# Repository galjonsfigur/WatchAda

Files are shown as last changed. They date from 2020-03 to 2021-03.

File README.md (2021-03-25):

# Ada-powereded digital watch

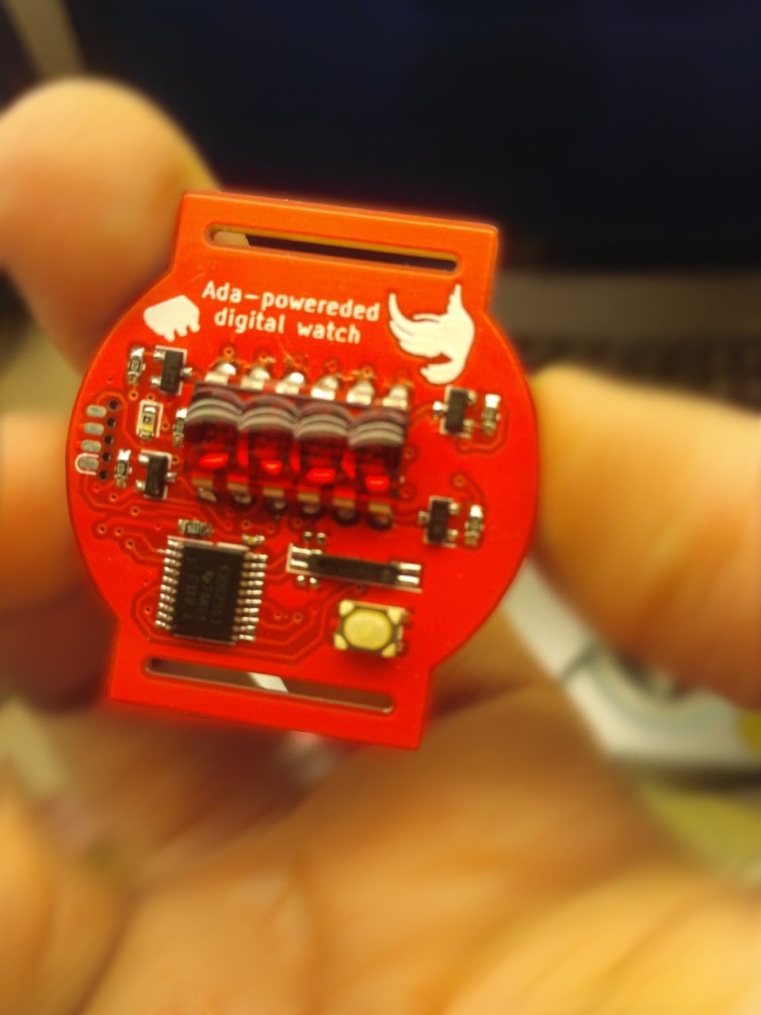
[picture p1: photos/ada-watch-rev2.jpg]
Digital watch


This repository contains Schematics, KiCad design files and software for Ada-powereded digital watch.
It uses wonderful work of [msp430-ada project](https://sourceforge.net/projects/msp430ada/) by Brian Drummond.
Software for this watch is a modification of original project and adds missing
features like automatic brightness, temperature reading and Easter Egg.

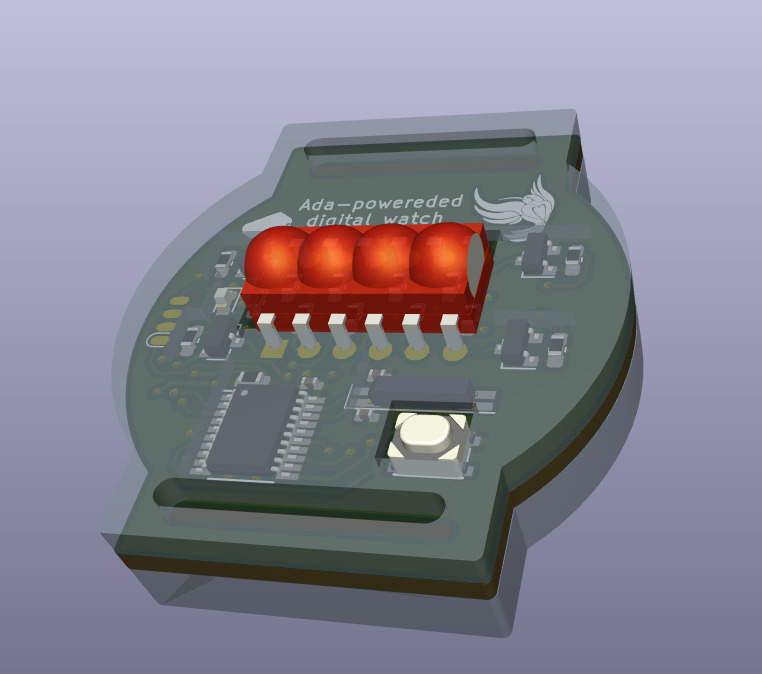
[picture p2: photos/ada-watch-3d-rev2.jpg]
Digital watch 3D view


Revision 1 of the PCB was tested and following problems have been found:

- Incorrect footprint of CR2032 Battery holder
- THT Crystal footprint is too big and will be replaced with Epson MC-146 32kHz Crystal

Revision 2 fixed those problems and after about year of testing it haven't showed other flaws.
More photos and renders can be found in `photos` folder.

GCC compiler for building this project can be found in this repository. It was built on CentOS 6 x64 and should work with any modern 64-bit GNU/Linux distribution.
Docker image for it is still in progress as it requires exact same version of host GCC and patches from MSP430-Ada project.

## BOM and assembly instructions
Interactive BOM can be found [here](hardware/rev2/bom/ibom.html).

Remember to start with SMD components. Program the MSP430, put the display in place and
test it before soldering it to the board.

Case can be 3D printed with semi-transparent material or cut from thin PMMA.

The best way to program the microcontroller is to use [SOICBite](https://github.com/SimonMerrett/SOICbite) connected
to MSP430-G2 Launchpad. Pin layout can be found in the schematic and only TEST, RST, GND and 3V need to be used to program it.
After connecting the SOICBite, `make flash` command can be used. It uses `mspdebug` program and works only on GNU/Linux environment.
The firmware binary can be found in `firmware/obj` folder.

# License
GPL (Same as MSP430-Ada project)

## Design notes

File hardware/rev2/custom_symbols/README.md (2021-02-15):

# Third-party symbols used in this design:

- [SOICBite](https://github.com/SimonMerrett/SOICbite)
- [SKRPACE010](https://github.com/nosuz/kicad-lib) (footprint only)
- [MC146 Crystal](https://grabcad.com/library/crystal-smd-seikoepson-mc146-4pin-6-7x1-5mm-1)

Rest of the files were designed for this project by its author.

This folder also contains fused model of the case to be able to see how it would
align with the PCB - to display it [this](custom_case_fused.step) 3D model has
to be attached to any component and aligned.

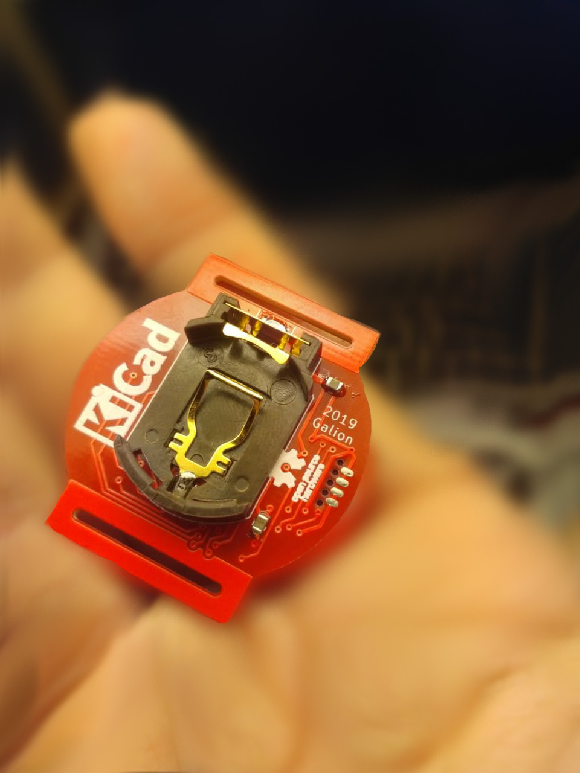
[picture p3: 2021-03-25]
photos/ada-watch-back-rev2.jpg

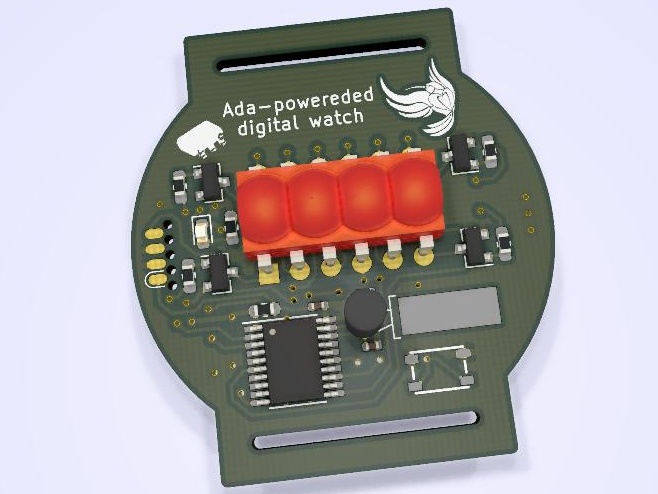
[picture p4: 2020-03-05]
photos/ada-watch-3d-rev1.jpg

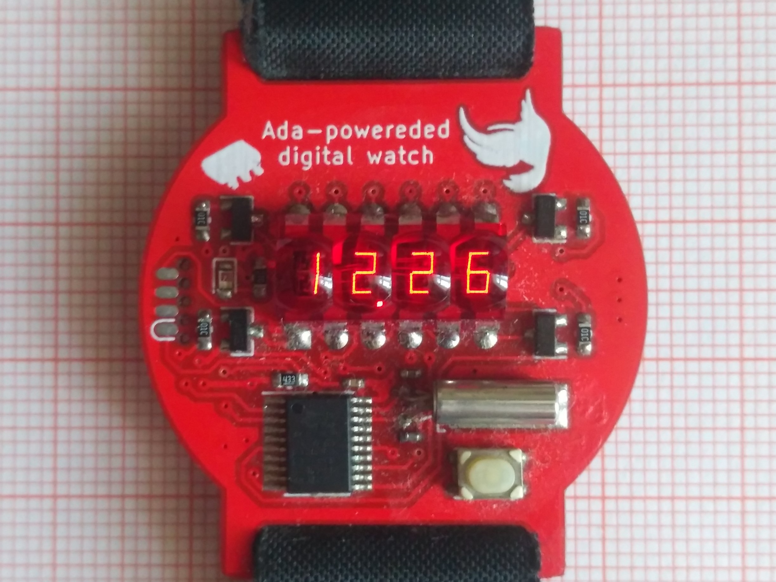
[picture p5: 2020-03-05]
photos/front-rev1.jpg

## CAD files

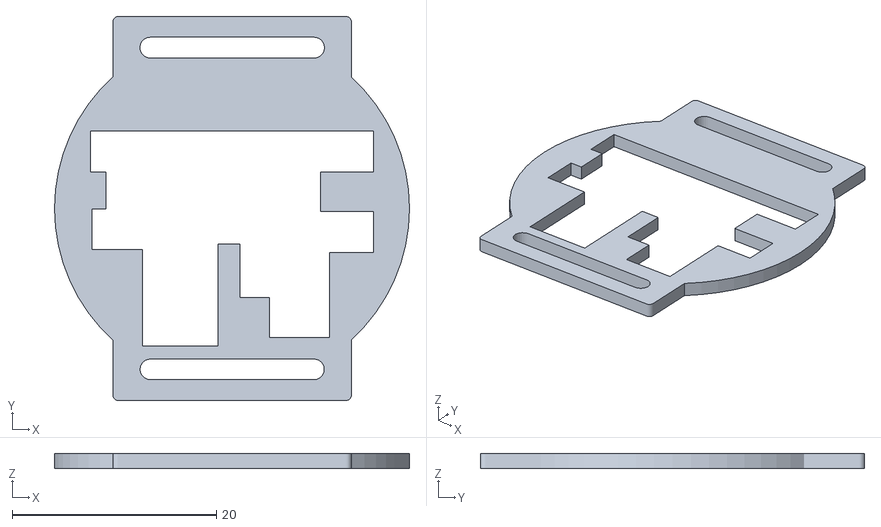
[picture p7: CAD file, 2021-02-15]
case/Front_PCB.obj
34.8 x 37.6 x 1.50

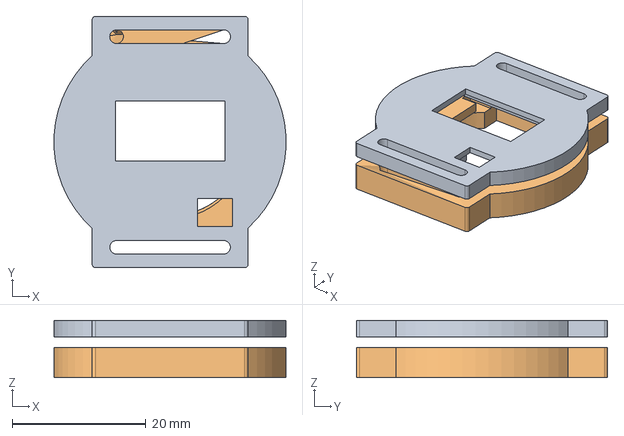
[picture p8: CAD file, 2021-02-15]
hardware/rev2/custom_symbols/custom_case_fused.step
34.7 x 37.6 x 8.60 mm

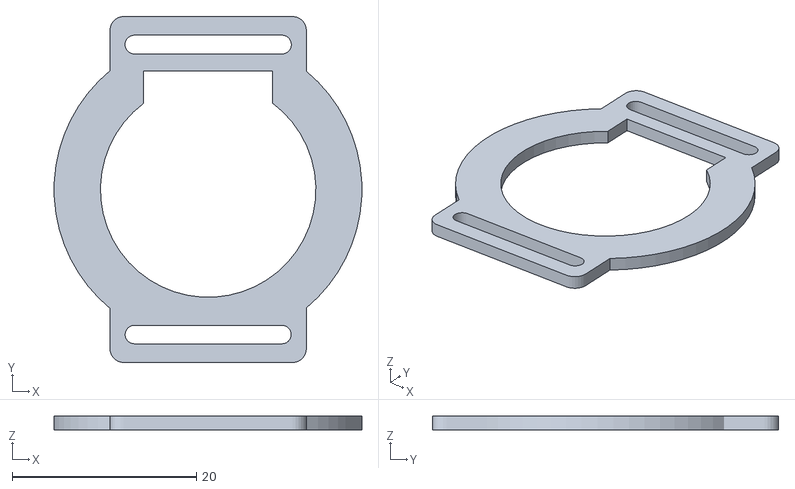
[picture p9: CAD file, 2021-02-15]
case/Back_Middle_Cover.obj
33.4 x 37.6 x 1.50

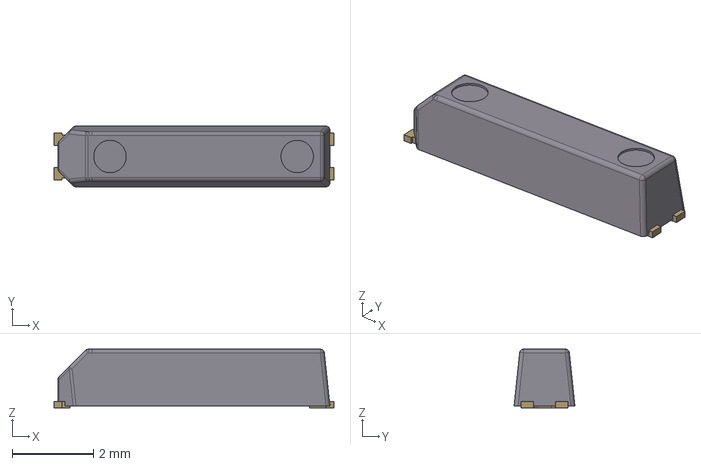
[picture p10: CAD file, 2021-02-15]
hardware/rev2/custom_symbols/Crystal_SMD_SeikoEpson_MC146-4Pin_6.7x1.5mm.step
6.90 x 1.50 x 1.45 mm

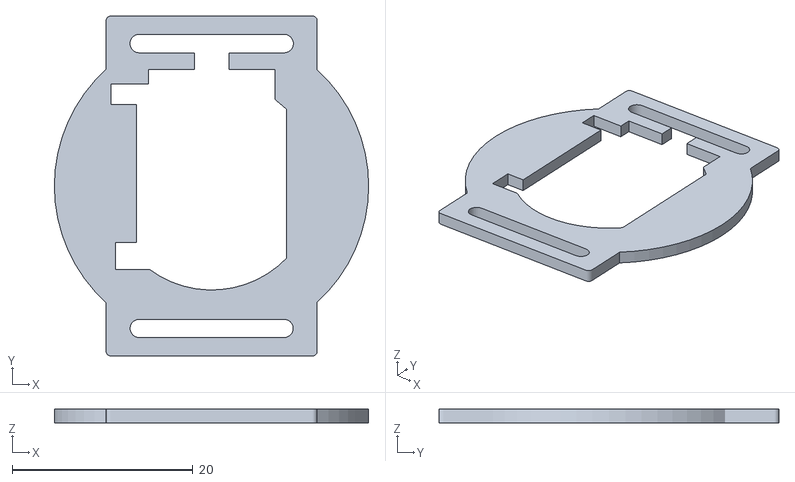
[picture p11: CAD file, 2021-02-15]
case/Back_PCB_Cover.obj
34.8 x 37.6 x 1.50

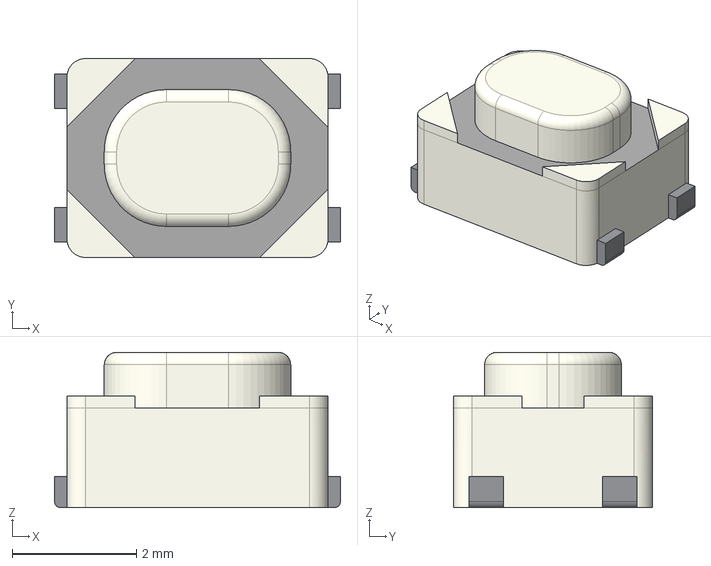
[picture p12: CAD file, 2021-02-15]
hardware/rev2/custom_symbols/SKRPACE010.step
4.60 x 3.20 x 2.50 mm

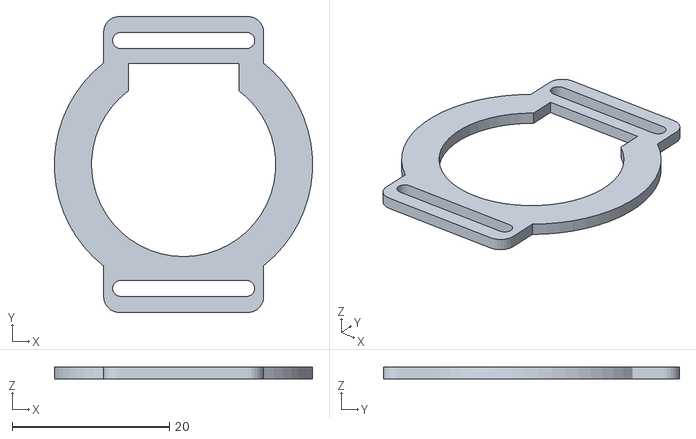
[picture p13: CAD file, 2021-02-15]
case/Back_Battery_Cover.obj
32.8 x 37.6 x 1.50

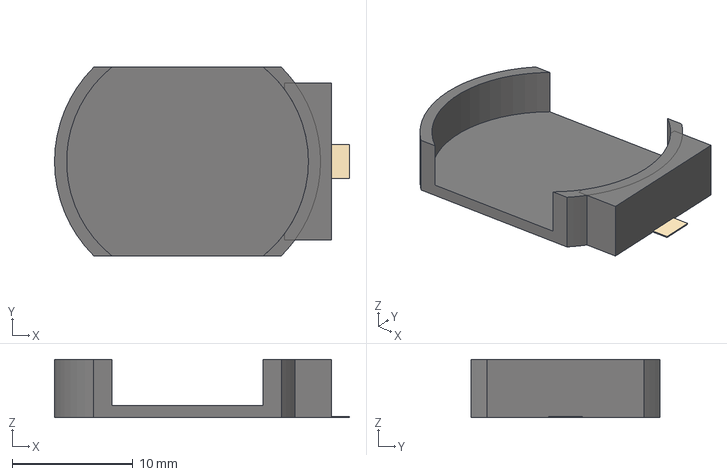
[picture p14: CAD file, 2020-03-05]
hardware/rev2/custom_symbols/CR2032_780-72-00GF51.step
24.4 x 15.6 x 4.80 mm

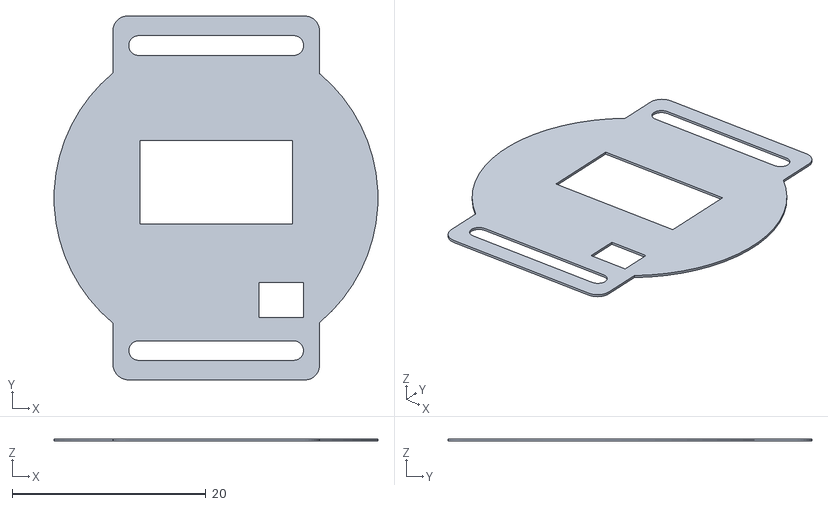
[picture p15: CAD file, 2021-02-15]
case/Front_Cover.obj
33.4 x 37.6 x 0.25

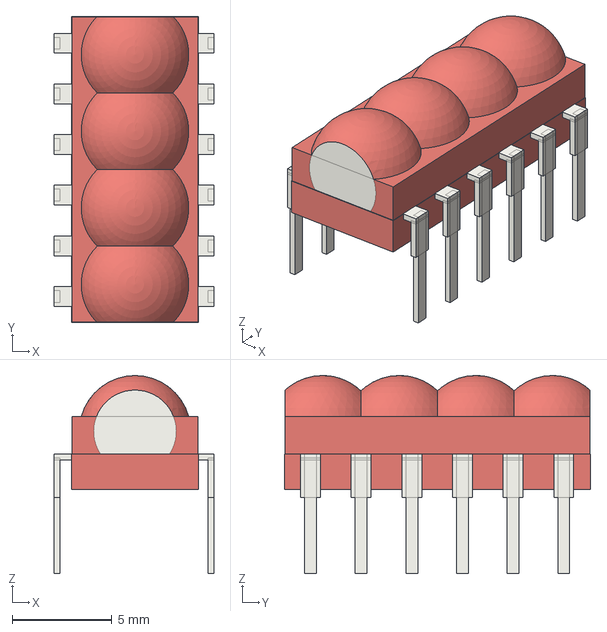
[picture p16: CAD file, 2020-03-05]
hardware/rev2/custom_symbols/HP5082-74x4.step
8.00 x 15.4 x 9.93 mm

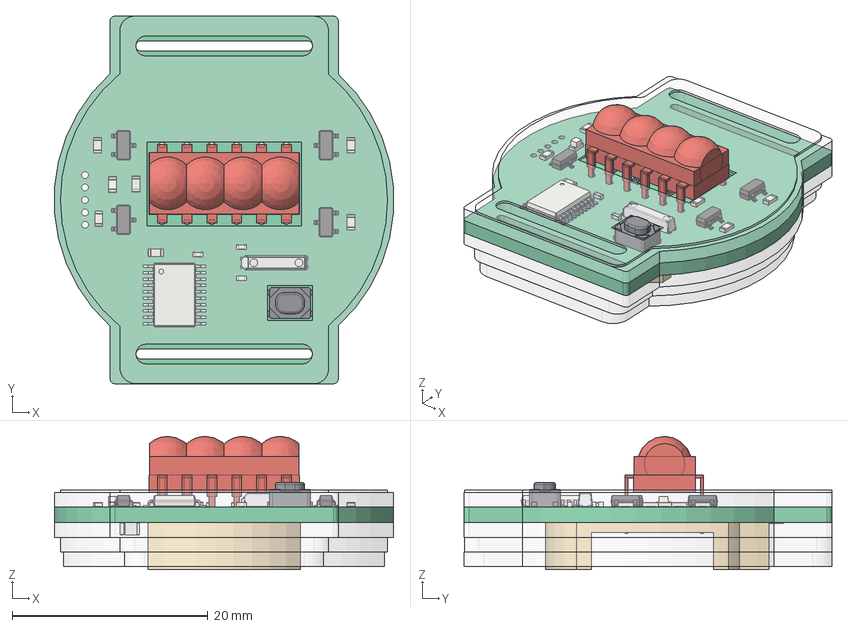
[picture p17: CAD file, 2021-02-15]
case/case.FCStd
34.7 x 37.6 x 13.6 mm
Pcb
"Y1"_Crystal_SMD_SeikoEpson_MC146-4Pin_6.7x1.5mm_00000000-0000-0000-0000-00005d9e574c[2]
"U1"_union_00000000-0000-0000-0000-00005d9e570d
"R9"_R_0603_1608Metric_00000000-0000-0000-0000-00005d9e5678
"U2"_TSSOP_20_44x65mm_P065mm_00000000-0000-0000-0000-00005d9e5731
"SW1"_SKRPACE101_00000000-0000-0000-0000-00005d9e56dd
"R14"_R_0603_1608Metric_00000000-0000-0000-0000-00005d9e56cd
"R13"_R_0603_1608Metric_00000000-0000-0000-0000-00005d9e56bc
"R12"_R_0603_1608Metric_00000000-0000-0000-0000-00005d9e56ab
"R11"_R_0603_1608Metric_00000000-0000-0000-0000-00005d9e569a
"R10"_R_0603_1608Metric_00000000-0000-0000-0000-00005d9e5689
"R8"_R_0603_1608Metric_00000000-0000-0000-0000-00005d9e5667
"R7"_R_0603_1608Metric_00000000-0000-0000-0000-00005d9e5656
"R6"_R_0603_1608Metric_00000000-0000-0000-0000-00005d9e5645
"R5"_R_0603_1608Metric_00000000-0000-0000-0000-00005d9e5634
"R4"_R_0603_1608Metric_00000000-0000-0000-0000-00005d9e5623
"R3"_R_0603_1608Metric_00000000-0000-0000-0000-00005d9e5612
"R2"_R_0603_1608Metric_00000000-0000-0000-0000-00005d9e5601
"R1"_R_0603_1608Metric_00000000-0000-0000-0000-00005d9e55f0
"Q5"_LED_0603_1608Metric_00000000-0000-0000-0000-00005da37bf8
"Q4"_SOT_23_00000000-0000-0000-0000-00005d9e55cc
"Q3"_SOT_23_00000000-0000-0000-0000-00005d9e55b7
"Q2"_SOT_23_00000000-0000-0000-0000-00005d9e55a2
"Q1"_SOT_23_00000000-0000-0000-0000-00005d9e558d
"C5"_C_0402_1005Metric_00000000-0000-0000-0000-00005d9e5560
"C4"_C_0402_1005Metric_00000000-0000-0000-0000-00005d9e5551
"C3"_C_0402_1005Metric_00000000-0000-0000-0000-00005d9e5542
"BT1"_union001_00000000-0000-0000-0000-00005e064094
"C2"_C_0805_2012Metric_00000000-0000-0000-0000-00005d9e5533
"C1"_C_0805_2012Metric_00000000-0000-0000-0000-00005d9e5522

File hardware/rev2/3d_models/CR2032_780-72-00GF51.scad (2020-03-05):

translate([-1.7, 0, 0])
union() {
    color("Black") intersection(){
        translate([-11.895, -7.8]) cube([23.79, 15.6, 4.8]);
        difference() {
            union() {           
                cylinder(h=4.8, d=22);
                translate([8, -6.5, 0]) cube([4.79, 13, 4.8]);
            }
                translate([0, 0, 1]) cylinder(h=3.8, d=20);    
        }
    }
    color("Gold") {
        translate([-10.5, -0.9, 0]) cube([4, 1.8, 0.1]);
     translate([22.79/2, -1.4, 0]) cube([2, 2.8, 0.1]);   
    }
}

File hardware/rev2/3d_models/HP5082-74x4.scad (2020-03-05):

rotate([0,0,90])
translate([-6.35, -3.81 ,1.78/2])
union() {
    color("Red") {
    cube([15.37, 6.35, 1.78], center=true);
    translate([0, 0, 1.78])
    cube([15.3, 6.3, 2], center=true);
    intersection(){
    for(i = [0:3]) {
        translate([-15.37/2+1.92125+i*1.92125*2, 0, 2.03])
            color("Red") sphere(r=2.8, $fn=50);
    }
    cube([15.3, 6.3, 15], center=true);
    }
}
    translate([-5.08 - 2.54, 0, -0.9])
    for (i = [0:5]) {
    color("Silver") translate([i*2.54,-3.5,0]) {
    	translate([1.252 - 0.5, -0.45, 1.5])
    	    cube([1, 5, 0.3]);
    	translate([1.252-0.5, 2.55, 1.5])
    	    cube([1, 5, 0.3]);
    	translate([1.252-0.3, -0.45, -4.2])
            cube([0.6, 0.3, 6]);
    	translate([1.252 - 0.3, 7.25,-4.2])
            cube([0.6, 0.3, 6]);
    	translate([1.252 - 0.5, -0.45, -0.4])
            cube([1, 0.3, 2]);
    	translate([1.252 - 0.5, 7.25, -0.4])
            cube([1, 0.3, 2]);
    }
}
 
}

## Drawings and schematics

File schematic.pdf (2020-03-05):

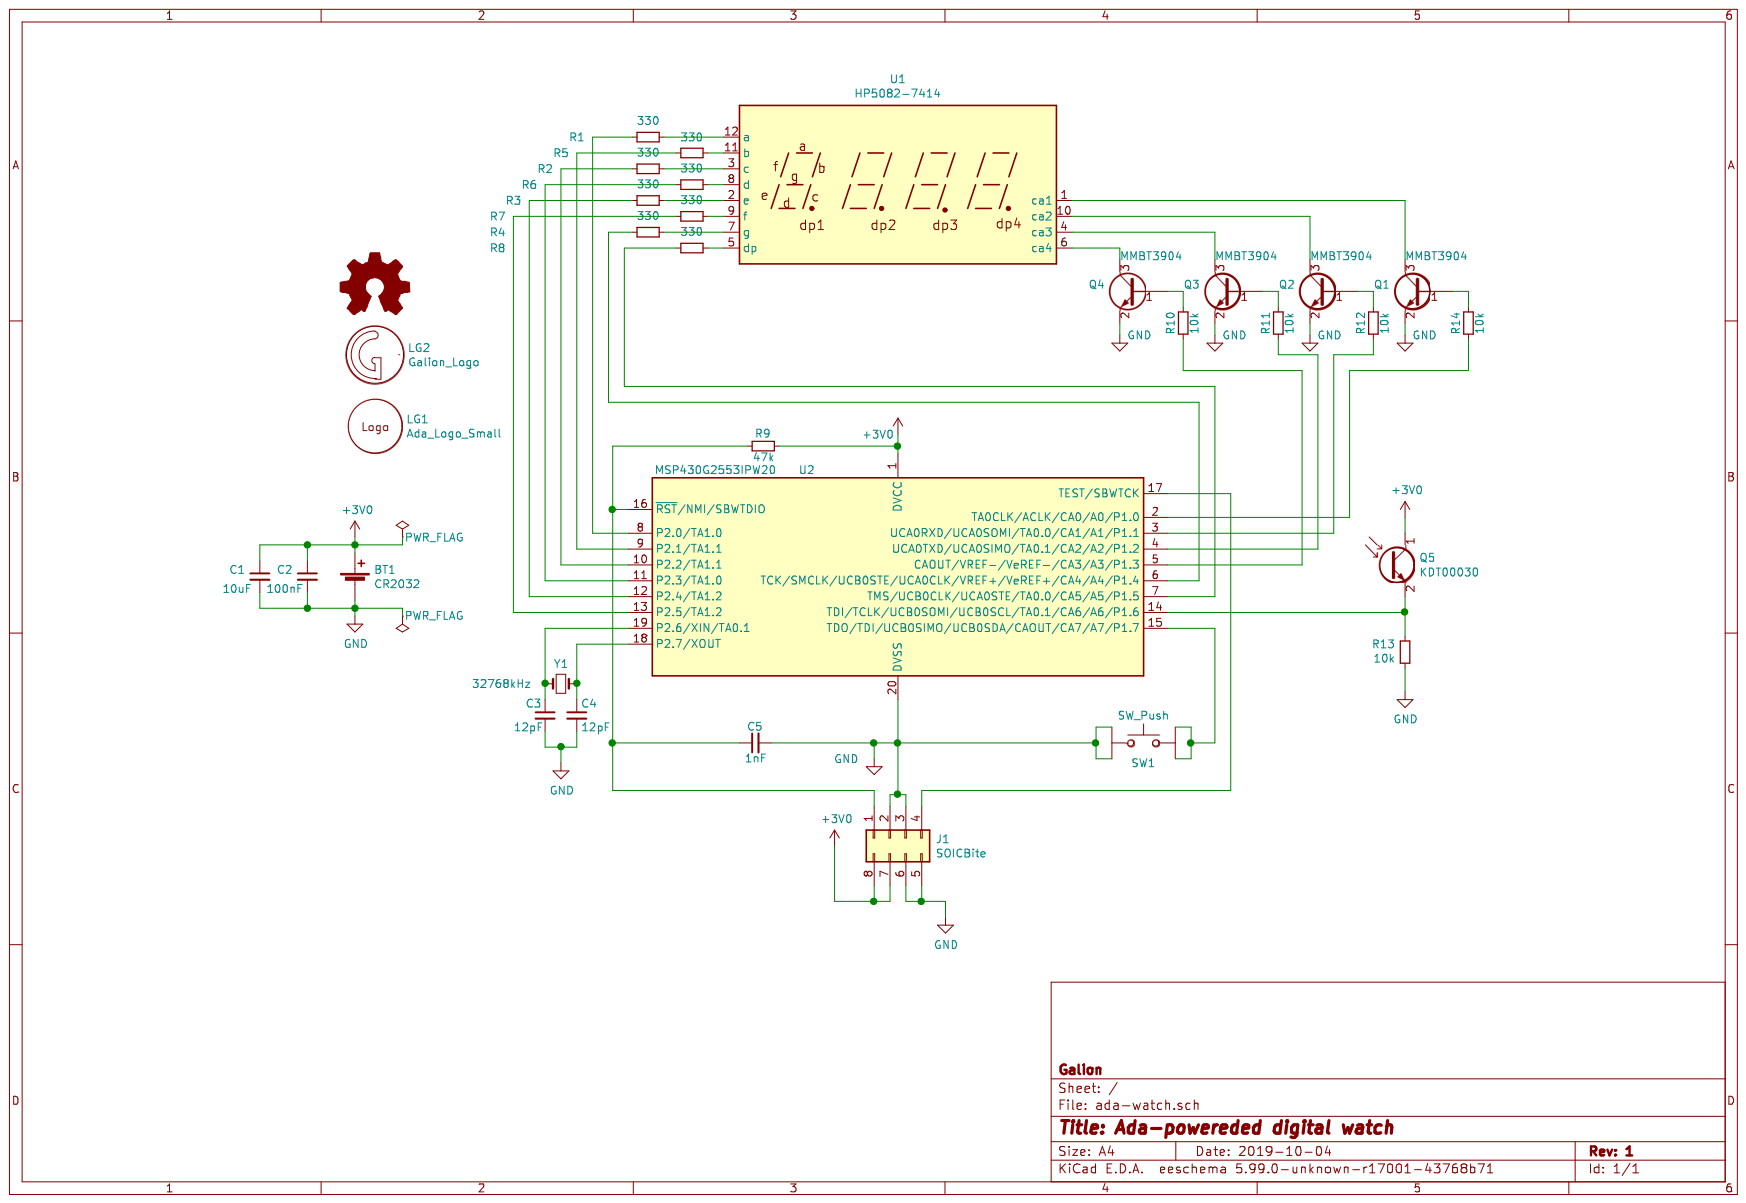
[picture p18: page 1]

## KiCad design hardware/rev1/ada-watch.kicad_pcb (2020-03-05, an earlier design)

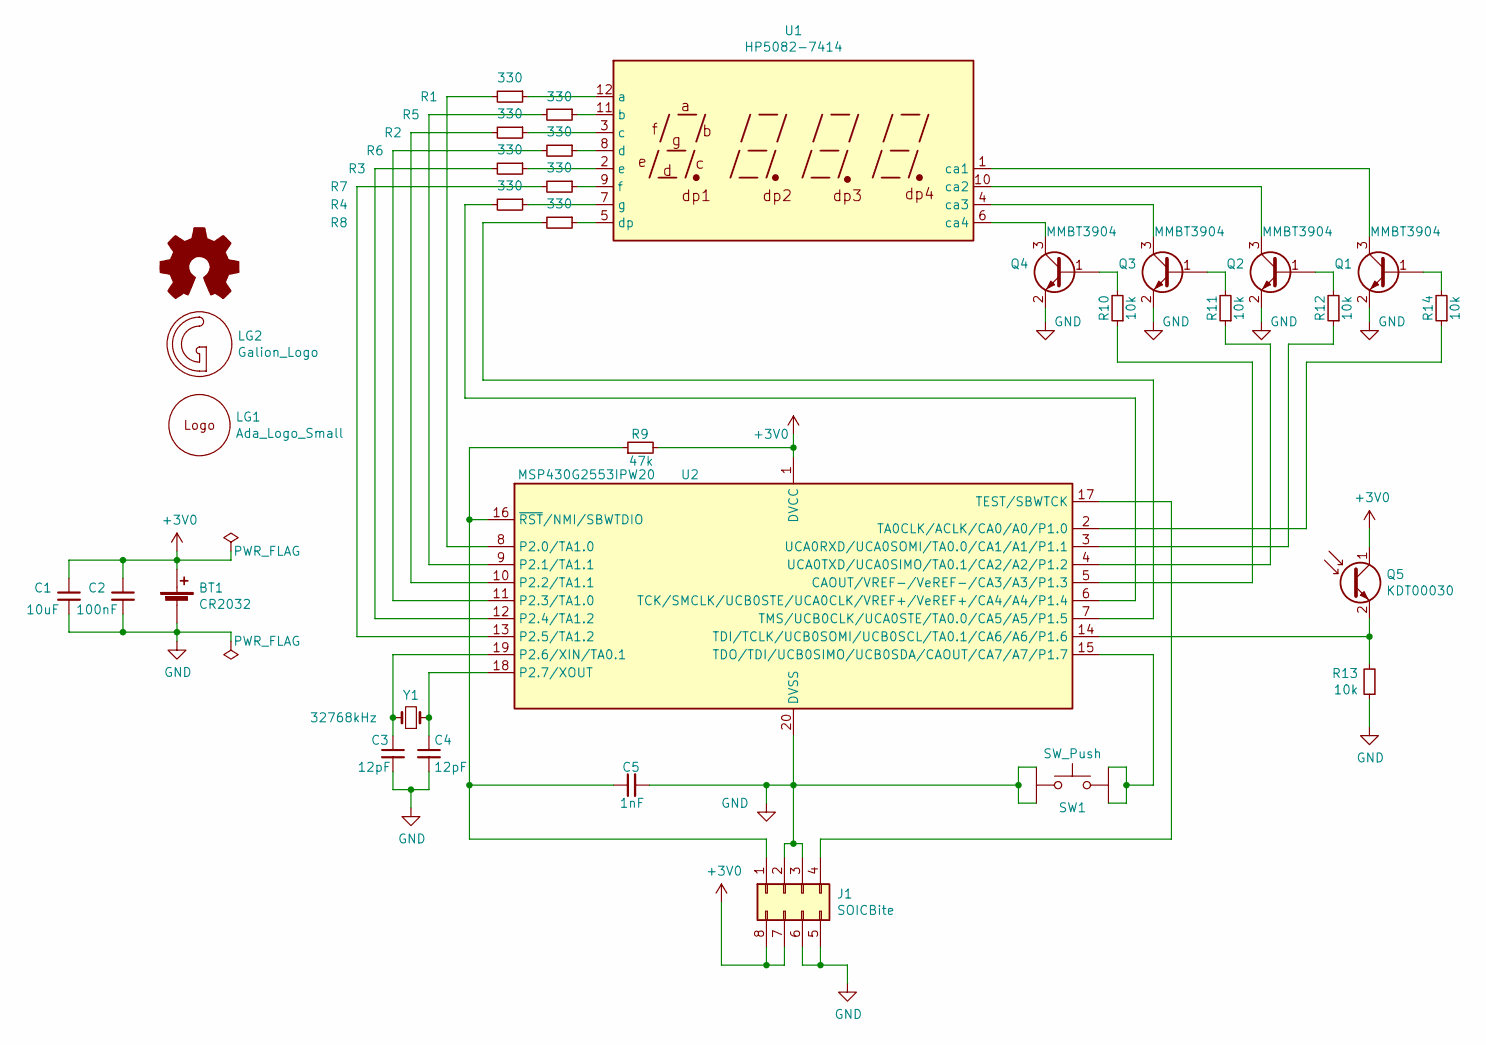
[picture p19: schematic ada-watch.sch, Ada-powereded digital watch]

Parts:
BT1: CR2032; BatteryHolder_Pinrex_780-72-00GF51_1x2032_customSilk
C1: 10uF; C_0805_2012Metric
C2: 100nF; C_0805_2012Metric
C3, C4: 12pF; C_0402_1005Metric
C5: 1nF; C_0402_1005Metric
J1: SOICBite; SOIC_clipProgSmall
LG1: Ada_Logo_Small
LG2: Galion_Logo; Galion_Logo_Small
LG3: Logo_Open_Hardware_Small; OSHW-Symbol_6.7x6mm_SilkScreen
Q1, Q2, Q3, Q4: MMBT3904; SOT-23
Q5: KDT00030; LED_0603_1608Metric
R1, R2, R3, R4, R5, R6, R7, R8: 330; R_0603_1608Metric_Pad1.05x0.95mm_HandSolder
R9: 47k; R_0603_1608Metric
R10, R11, R12, R13, R14: 10k; R_0603_1608Metric_Pad1.05x0.95mm_HandSolder
SW1: SW_Push; SKRPACE010
U1: HP5082-7414; DIP-12_W7.62mm_CustomPads_NoSilk
U2: MSP430G2553IPW20; TSSOP-20_4.4x6.5mm_P0.65mm
Y1: 32768kHz; Crystal_C38-LF_D3.0mm_L8.0mm_Horizontal_1EP_style1

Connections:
+3V0: BT1.1 (+), C1.1, C2.1, J1.7, J1.8, Q5.1 (C), R9.2, U2.1 (DVCC)
GND: BT1.2 (-), C1.2, C2.2, C3.2, C4.2, C5.2, J1.2, J1.3, J1.5, J1.6, Q1.2 (E), Q2.2 (E), Q3.2 (E), Q4.2 (E), R13.1, SW1.3, SW1.4, U2.20 (DVSS)
unnamed: C3.1, U2.19 (P2.6/XIN/TA0.1), Y1.2
unnamed: C4.1, U2.18 (P2.7/XOUT), Y1.1
unnamed: C5.1, J1.1, R9.1, U2.16 (~RST~/NMI/SBWTDIO)
unnamed: J1.4, U2.17 (TEST/SBWTCK)
unnamed: Q1.1 (B), R14.2
unnamed: Q1.3 (C), U1.1 (ca1)
unnamed: Q2.1 (B), R12.2
unnamed: Q2.3 (C), U1.10 (ca2)
unnamed: Q3.1 (B), R11.2
unnamed: Q3.3 (C), U1.4 (ca3)
unnamed: Q4.1 (B), R10.2
unnamed: Q4.3 (C), U1.6 (ca4)
unnamed: Q5.2 (E), R13.2, U2.14 (TDI/TCLK/UCB0SOMI/UCB0SCL/TA0.1/CA6/A6/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)
unnamed: R1.1, U1.12 (a)
unnamed: R1.2, U2.8 (P2.0/TA1.0)
unnamed: R2.1, U1.3 (c)
unnamed: R2.2, U2.10 (P2.2/TA1.1)
unnamed: R3.1, U1.2 (e)
unnamed: R3.2, U2.12 (P2.4/TA1.2)
unnamed: R4.1, U1.7 (g)
unnamed: R4.2, U2.6 (TCK/SMCLK/UCB0STE/UCA0CLK/VREF+/VeREF+/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)
unnamed: R5.1, U1.11 (b)
unnamed: R5.2, U2.9 (P2.1/TA1.1)
unnamed: R6.1, U1.8 (d)
unnamed: R6.2, U2.11 (P2.3/TA1.0)
unnamed: R7.1, U1.9 (f)
unnamed: R7.2, U2.13 (P2.5/TA1.2)
unnamed: R8.1, U1.5 (dp)
unnamed: R8.2, U2.7 (TMS/UCB0CLK/UCA0STE/TA0.0/CA5/A5/P1.5)
unnamed: R10.1, U2.5 (CAOUT/VREF-/VeREF-/CA3/A3/P1.3)
unnamed: R11.1, U2.4 (UCA0TXD/UCA0SIMO/TA0.1/CA2/A2/P1.2)
unnamed: R12.1, U2.3 (UCA0RXD/UCA0SOMI/TA0.0/CA1/A1/P1.1)
unnamed: R14.1, U2.2 (TA0CLK/ACLK/CA0/A0/P1.0)
unnamed: SW1.1, SW1.2, U2.15 (TDO/TDI/UCB0SIMO/UCB0SDA/CAOUT/CA7/A7/P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)

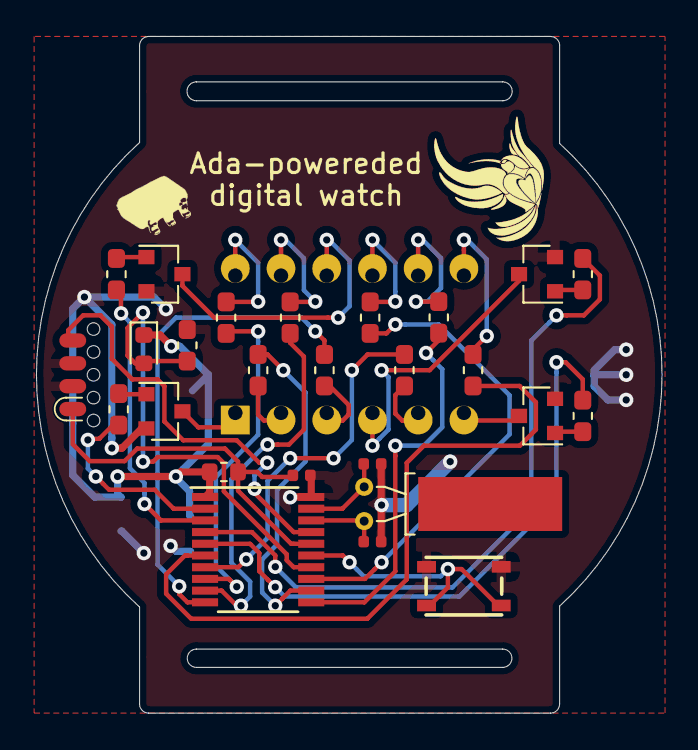
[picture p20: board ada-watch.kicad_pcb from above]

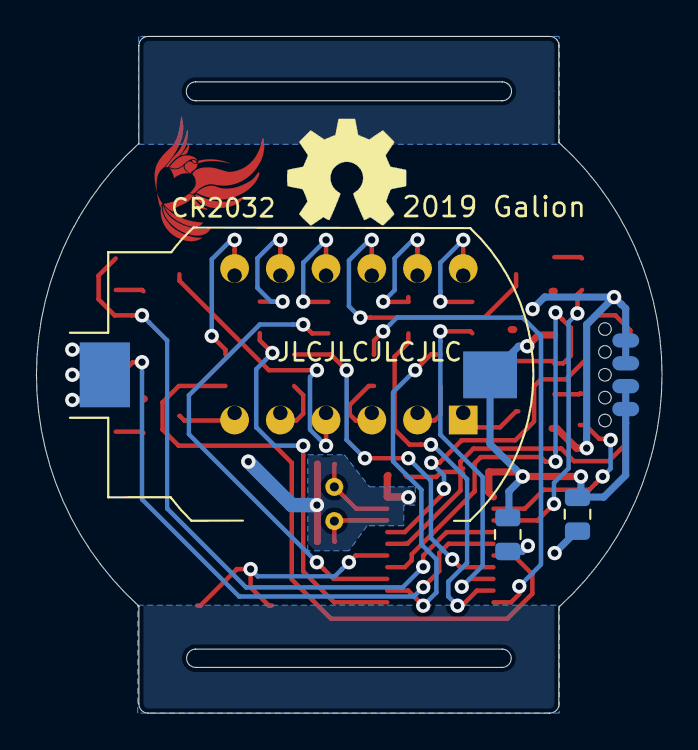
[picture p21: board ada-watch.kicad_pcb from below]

Board: 2 copper layers, 34.8 x 37.6 mm, 33 parts (4 on the bottom side), 36 nets.

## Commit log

2021-02-15 Add revision 2 of the PCB
    [CR2032_780-72-00GF51.scad, CR2032_780-72-00GF51.step, Crystal_SMD_SeikoEpson_MC146-4Pin_6.7x1.5mm.step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]
2021-02-15 Add case files
    [Back_Battery_Cover.obj, Back_Middle_Cover.obj, Back_PCB_Cover.obj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]
